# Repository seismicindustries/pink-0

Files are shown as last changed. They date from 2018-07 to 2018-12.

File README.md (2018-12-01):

<!--- View this project on [CADLAB.io](https://cadlab.io/project/1079). -->

# (s)pink-0
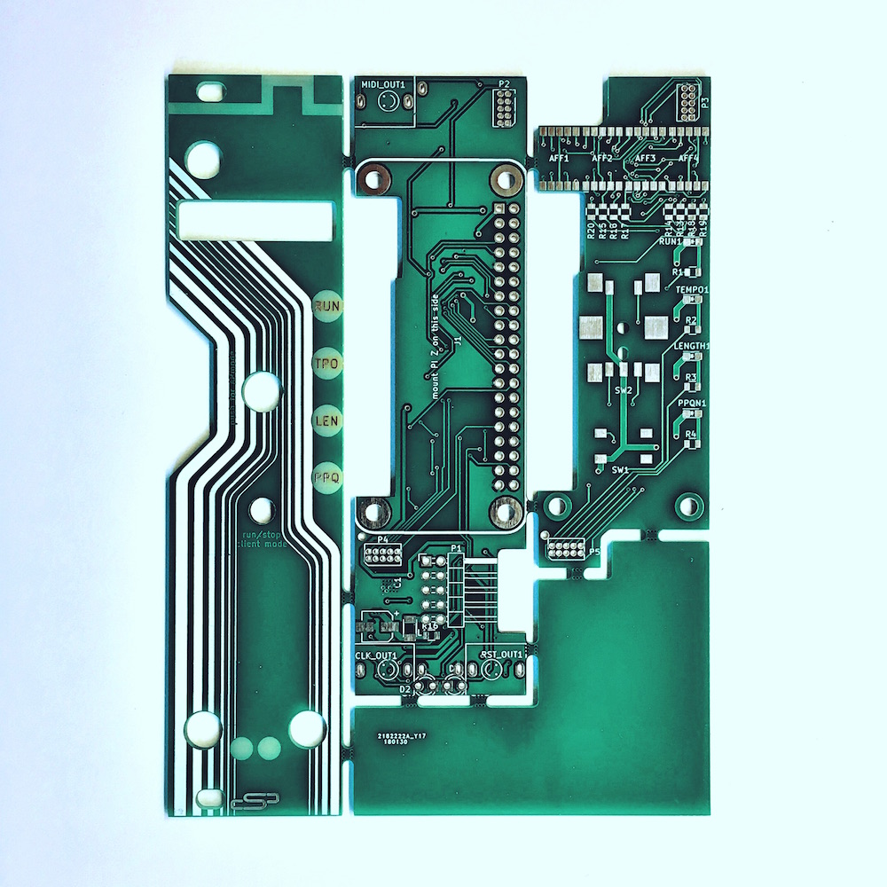
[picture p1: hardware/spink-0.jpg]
pic of the spink-0 PCB adaption

This repository contains the source code and the schematics for an Ableton Link to clock/reset converter.

And the necessary changes & hardware files for the spink-0 adaption

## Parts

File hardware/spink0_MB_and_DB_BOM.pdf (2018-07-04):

spink0 Mainboard
Refs | Value | Footprint | QTY MFR | MPN | SPR | SPN
C1 | 22u | raffilibkicad:CP_Elec_5x5.3 | 1 Panasonic | EEE-FK1C220R | Mouser | 667-EEE-FK1C220R
C6 | 22u | raffilibkicad:CP_Elec_7.3x4.3 | 1 Panasonic | EEF-CX1D220R | Mouser | 667-EEF-CX1D220R
C7 | 100n | raffilibkicad:C_0805 | 1 AVX | 08055C104KAT2A | Mouser | 581-08055C104K
C3 | 1u | raffilibkicad:C_0805 | 1 Yageo | CC0805MKY5V9BB105 Mouser | 603-CC805MKY5V9BB105
C4;C5 | 33n | raffilibkicad:C_0805 | 2 Kemet | C0805C333K5RACTU Mouser | 80-C0805C333K5R
L1 | INDUCTOR | raffilibkicad:Inductor_PSU_NLCV32T | 1 TDK | NLCV32T-R10M-PFR | Mouser | 810-NLCV32T-R10M-PFR
L3 | 6.8uH | raffilibkicad:Inductor_SRN4018TA_bourns | 1 Bourns | SRN4018TA-6R8M | Mouser | 652-SRN4018TA-6R8M
D2;D1 | LED | raffilibkicad:LED_D3.0mm | 2 Lite-On | LTL-4231N | Mouser | 859-LTL-4231N
P2;P4 | CONN_02X05 | raffilibkicad:PINHEAD_10_pin_jtag_connector 2 Amphenol FCI | 20021111-00010T4LF Mouser | 649-221111-00010T4LF
J1 | PI_ZERO | raffilibkicad:PI_ZERO | 1 | | your PI supplier
P1 | CONN_02X05 | raffilibkicad:Pin_Header_Angled_2x05_Pitch2.54mm_with_space_for_con 1 Amphenol FCI | 649-68020-110HLF | Mouser | 68020-110HLF
R16 | 100k | raffilibkicad:R_0805 | 1 Yageo | RC0805FR-07100KL | Mouser | 603-RC0805FR-07100KL
R5;R6;R21;R24;R23 | 10k | raffilibkicad:R_0805 | 5 Vishay | CRCW080510K0FKEAC Mouser | 71-CRCW080510K0FKEAC
R10;R7;R9;R8;R12;R11;R13;R4;R14;R15;R17;R18 1k | raffilibkicad:R_0805 | 12 Vishay | CRCW08051K00FKEAC Mouser | 71-CRCW08051K00FKEAC
R22 | 220 | raffilibkicad:R_0805 | 1 Bourns | CR0805-FX-2200GLF | Mouser | 652-CR0805-FX2200GLF
R2 | 40k2 | raffilibkicad:R_0805 | 1 Yageo | RC0805FR-0740K2L | Mouser | 603-RC0805FR-0740K2L
R1 | 75k | raffilibkicad:R_0805 | 1 Vishay | CRCW080575K0FKEA Mouser | 71-CRCW0805-75K-E3
R3 | 7k68 | raffilibkicad:R_0805 | 1 Yageo | RC0805FR-077K68L | Mouser | 603-RC0805FR-077K68L
Q1;Q2;Q3;Q4 | BC849 | raffilibkicad:SOT-23 | 4 | | Mouser | 771-BC849C-T/R
U1 | MP1469 | raffilibkicad:SOT-23-6 | 1 MPS | MP1469GJ-Z | Mouser | 946-MP1469GJZ
U2 | MCP6004 | raffilibkicad:TSSOP-14_4.4x5mm_Pitch0.65mm 1 Microchip Techology MCP6004-I/ST | Mouser | 579-MCP6004-I/ST
CLK_OUT1;RST_OUT1 | JACK_QINGPU | raffilibkicad:jack_qingpu | 2 | a.k.a. thonkicon
MIDI_OUT1 | TRS stereojack | raffilibkicad:jack_qingpu | 1 maybe green thonkicon or -> | Mouser | 161-3402-E
J6;J5;J8;J7 | GS3 | raffilibkicad:solderbridge | 4

spink0 Displayboard
Refs | Value | Footprint | QTY MFR | MPN | SPR | SPN
RUN1;TEMPO1;LENGTH1;PPQN1 | LED | LEDs:LED_0805 | 4 Kingbright | APHCM2012CGCK-F01 Mouser | 604-APHCM2012CGCK
AFF1;AFF2;AFF3;AFF4 | 7SEGMENTS | raffilibkicad:ACSA02_KCSA02_7segment | 4 Kingbright | ACSA02-41SGWA-F01 Mouser | 604-ACSA02-41SGWA
SW1 | SW_PUSH_SMALL_H | raffilibkicad:APEM_tactile_SMD_switch_6mm 1 APEM | ADTSM66NV | Mouser | 642-ADTSM66NV
SW2 | Rotary_Encoder_Switch raffilibkicad:ENCODER_PEC11_SMD | 1 Bourns | PEC11S-929K-S0015 | Mouser | 652-PEC11S9215KH0015
R1;R2;R3;R4;R13;R14;R15;R16;R17;R18;R19;R20 100 | raffilibkicad:R_0805 | 12 Yageo | RC0805FR-07100RL | Mouser | 603-RC0805FR-07100RL

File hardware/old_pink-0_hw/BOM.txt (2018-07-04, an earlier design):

Resistors
12x  330R 0402 (R1 - R12)
2x   750R 0402 (R15, R16)
4x   1K   0402 (R17 - R20)
2x   10K  0402 (R13, R14)

Capacitors
2x   33n 0603  (C1, C2)

Transistors
2x   MMBT3904 (T1, T2)

LEDs
3x   LED 0603 yellow
1x   LED 0603 green

Connectors
2x   Erthenvar PJ301BM
1x   2x40 pin female header

Misc
1x   Display HP QDSP6064
1x   Rotary encoder w/ pushbutton
1x   6mm tactile switch
1x   Pink-0 pcb

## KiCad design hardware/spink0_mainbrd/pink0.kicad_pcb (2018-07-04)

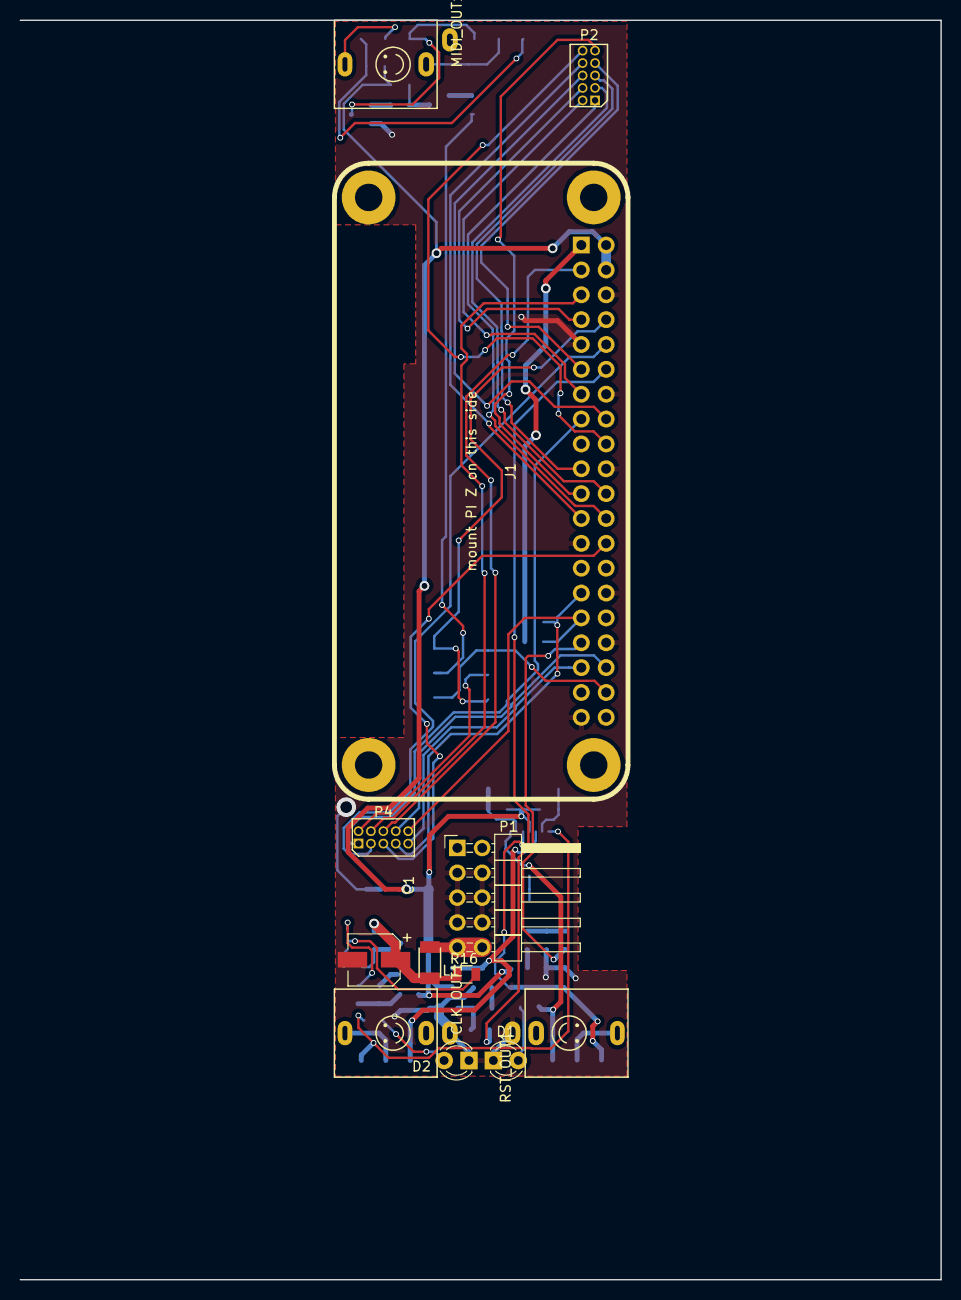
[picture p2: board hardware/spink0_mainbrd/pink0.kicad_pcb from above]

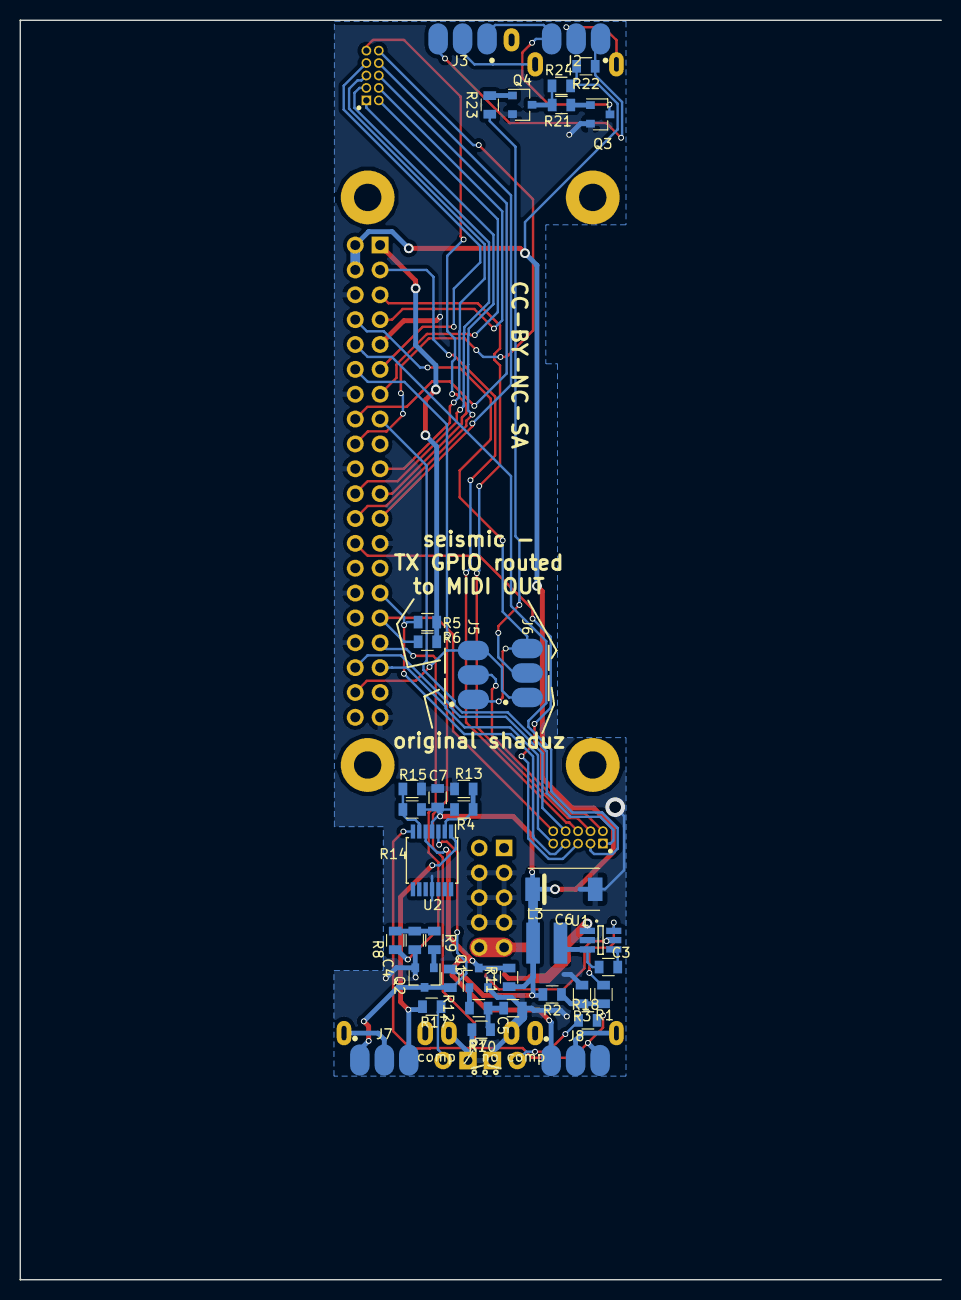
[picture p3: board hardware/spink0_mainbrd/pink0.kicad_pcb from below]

Board: 2 copper layers, 94.1 x 128.7 mm, 51 parts (39 on the bottom side), 56 nets.

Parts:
C1: 22u; CP_Elec_5x5.3
C3: 1u; C_0805
C4, C5: 33n; C_0805
C6: 22u; CP_Elec_7.3x4.3
C7: 100n; C_0805
CLK_OUT1: JACK_QINGPU; jack_qingpu
D1, D2: LED; LED_D3.0mm
J1: PI_ZERO
J2, J3, J5, J6, J7, J8: GS3; solderbridge
L1: INDUCTOR; Inductor_PSU_NLCV32T
L3: 6.8uH; Inductor_SRN4018TA_bourns
MIDI_OUT1: JACK_QINGPU; jack_qingpu
P1: CONN_02X05; Pin_Header_Angled_2x05_Pitch2.54mm_with_space_for_con
P2, P4: CONN_02X05; PINHEAD_10_pin_jtag_connector
Q1, Q2, Q3, Q4: BC849; SOT-23
R1: 75k; R_0805
R2: 40k2; R_0805
R3: 7k68; R_0805
R4, R7, R8, R9, R10, R11, R12, R13, R14, R15, R17, R18: 1k; R_0805
R5, R6, R21, R23, R24: 10k; R_0805
R16: 100k; R_0805
R22: 220; R_0805
RST_OUT1: JACK_QINGPU; jack_qingpu
U1: MP1469; SOT-23-6
U2: MCP6004; TSSOP-14_4.4x5mm_Pitch0.65mm

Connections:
+3V3: J1.1, R5.1, R6.1
+5V: C6.1, C7.2, J1.2, J1.4, L3.1, R2.2, R4.1, R11.2, R12.2, R14.1, R22.1, R24.2, U2.4
+12VA: C1.1, L1.1, R16.1, U1.1
CLK_OUT: J8.1, Q1.3, R11.1, U2.5
Earth: C1.2, C4.2, C5.2, C6.2, C7.1, CLK_OUT1.1, D1.1, D2.1, J1.6, J1.9, J1.14, J1.20, J1.25, J1.30, J1.34, J1.39, P1.3, P1.4, P1.5, P1.6, P1.7, P1.8, Q1.2, Q2.2, Q3.2, Q4.2, R3.1, R13.2, R15.2, RST_OUT1.1, U1.2, U2.11
GPIO2: J1.3, P4.6
GPIO3: J1.5, P4.4
GPIO4: J1.7, P2.4
GPIO5: J1.29, P4.7, R5.2
GPIO6: J1.31, P4.10, R6.2
GPIO7: J1.26, P4.5
GPIO8: J1.24, P2.1
GPIO9: J1.21, P2.9
GPIO10: J1.19, P2.5
GPIO11: J1.23, P2.8
GPIO14: J1.8, J5.1, J6.3
GPIO15: J1.10, P4.3
GPIO16: J1.36, P4.8
GPIO17: J1.11, P2.7
GPIO19: J1.35, P4.9
GPIO20: J1.38, J5.3, J6.1
GPIO22: J1.15, P4.1
GPIO23: J1.16, P2.6
GPIO24: J1.18, P2.10
GPIO25: J1.22, P2.3
GPIO27: J1.13, P2.2
unnamed: C3.1, L3.2, U1.3
unnamed: C3.2, U1.4
unnamed: C4.1, R8.1, R9.2
unnamed: C5.1, R7.1, R10.2
unnamed: CLK_OUT1.3, J8.2
unnamed: D1.2, R17.1
unnamed: D2.2, R18.1
unnamed: J2.1, J3.3, R22.2
unnamed: J2.2, MIDI_OUT1.3
unnamed: J2.3, J3.1, Q3.3
unnamed: J3.2, MIDI_OUT1.2
unnamed: J6.2, R23.2
unnamed: J7.2, RST_OUT1.3
unnamed: J7.3, R17.2, U2.1
unnamed: J8.3, R18.2, U2.7
unnamed: L1.2, P1.9, P1.10
unnamed: Q1.1, R10.1
unnamed: Q2.1, R9.1
unnamed: Q3.1, R21.1
unnamed: Q4.1, R23.1
unnamed: Q4.3, R21.2, R24.1
unnamed: R1.1, U1.6
unnamed: R1.2, R2.1, R3.2
unnamed: R4.2, R13.1, U2.2
unnamed: R14.2, R15.1, U2.6
unnamed: R16.2, U1.5
PWMA_L: J1.12, R7.2
PWMA_R: J1.33, R8.2
RST_OUT: J7.1, Q2.3, R12.1, U2.3
T_LED: J5.2, P4.2

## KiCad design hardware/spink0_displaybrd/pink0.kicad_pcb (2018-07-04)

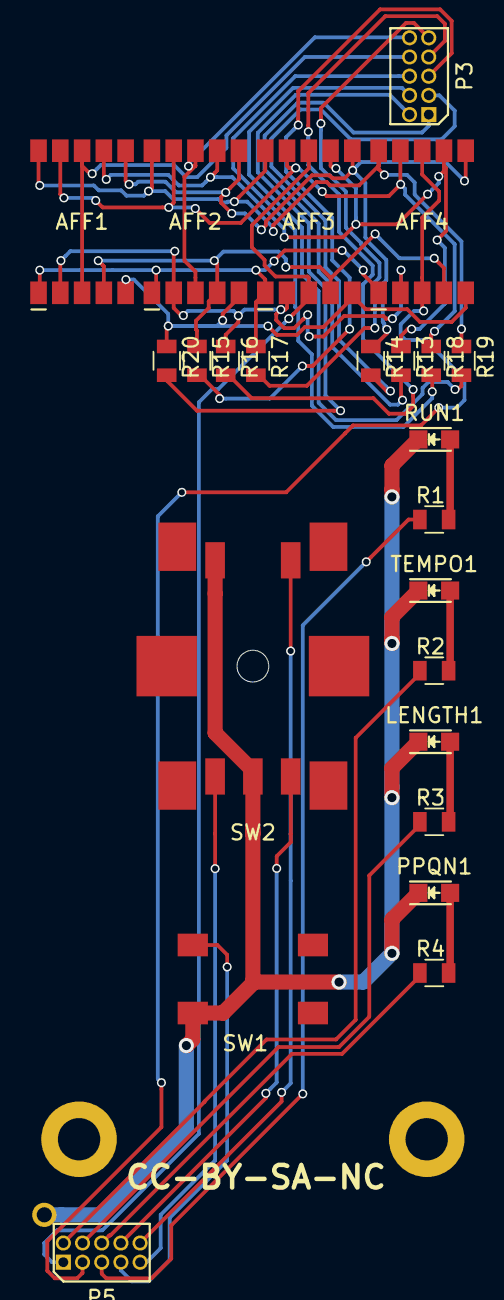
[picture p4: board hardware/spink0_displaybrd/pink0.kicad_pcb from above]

Board: 2 copper layers, 24 parts (0 on the bottom side), 33 nets.

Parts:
AFF1, AFF2, AFF3, AFF4: 7SEGMENTS; ACSA02_KCSA02_7segment
LENGTH1: LED; LED_0805
P3, P5: CONN_02X05; PINHEAD_10_pin_jtag_connector
PPQN1: LED; LED_0805
R1, R2, R3, R4, R13, R14, R15, R16, R17, R18, R19, R20: R; R_0805
RUN1: LED; LED_0805
SW1: SW_PUSH_SMALL_H; APEM_tactile_SMD_switch_6mm
SW2: Rotary_Encoder_Switch; ENCODER_PEC11_SMD
TEMPO1: LED; LED_0805

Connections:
A: AFF1.7, AFF2.7, AFF3.7, AFF4.7, R13.1
B: AFF1.6, AFF2.6, AFF3.6, AFF4.6, R14.1
C: AFF1.4, AFF2.4, AFF3.4, AFF4.4, R15.1
D: AFF1.2, AFF2.2, AFF3.2, AFF4.2, R16.1
DP: AFF1.5, AFF2.5, AFF3.5, AFF4.5, R20.1
E: AFF1.1, AFF2.1, AFF3.1, AFF4.1, R17.1
Earth: LENGTH1.1, PPQN1.1, RUN1.1, SW1.2, SW2.2, SW2.5, TEMPO1.1
F: AFF1.9, AFF2.9, AFF3.9, AFF4.9, R18.1
G: AFF1.10, AFF2.10, AFF3.10, AFF4.10, R19.1
GPIO2: P5.6, R4.1
GPIO3: P5.4, R3.1
GPIO4: P3.4, R19.2
GPIO5: P5.7, SW1.1
GPIO6: P5.10, SW2.4
GPIO7: P5.5, R1.1
GPIO8: P3.1, R13.2
GPIO9: P3.9, R17.2
GPIO10: P3.5, R15.2
GPIO11: AFF1.3, AFF1.8, P3.8
GPIO15: AFF4.3, AFF4.8, P5.3
GPIO16: P5.8, SW2.3
GPIO17: P3.7, R16.2
GPIO19: P5.9, SW2.1
GPIO22: AFF3.3, AFF3.8, P5.1
GPIO23: P3.6, R18.2
GPIO24: AFF2.3, AFF2.8, P3.10
GPIO25: P3.3, R14.2
GPIO27: P3.2, R20.2
unnamed: LENGTH1.2, R3.2
unnamed: PPQN1.2, R4.2
unnamed: R1.2, RUN1.2
unnamed: R2.2, TEMPO1.2
T_LED: P5.2, R2.1

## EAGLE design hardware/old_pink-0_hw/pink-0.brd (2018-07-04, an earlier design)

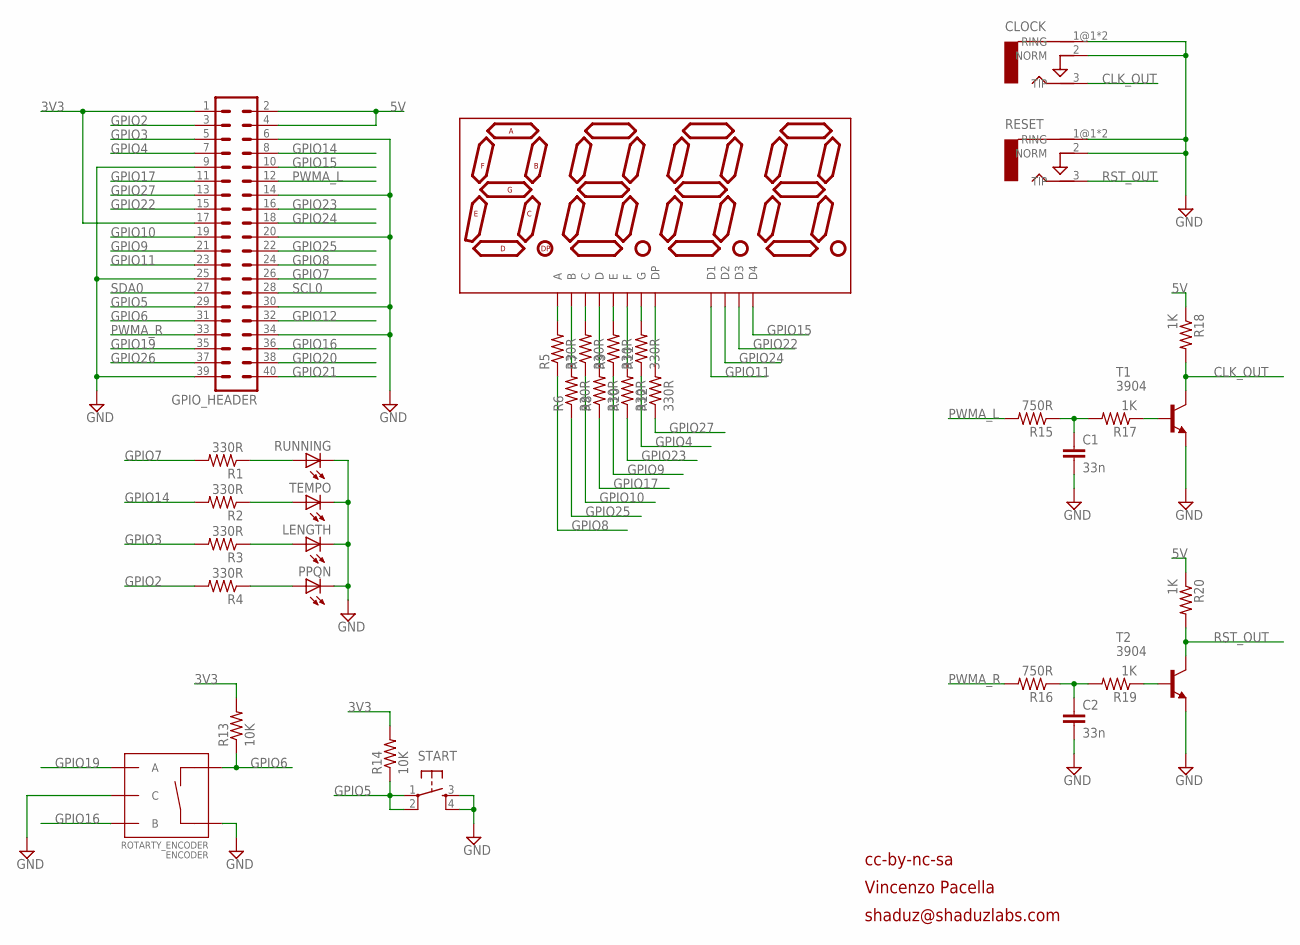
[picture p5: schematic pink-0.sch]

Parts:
C1, C2: 33n; 0603-CAP
CLOCK: AUDIO-JACKERTHENVAR; ERTHENVAR-JACK
DISP1: QDSP6064; DIL12
ENCODER: ROTARTY_ENCODER; ROTARY_ENC_PLAIN
GPIO_HEADER: PIZERO_THROUGH_HOLE; PIZERO_THOUGH_HOLE
LENGTH: LED0603; LED-0603
PPQN: LED0603; LED-0603
R1, R2, R3, R4, R5, R6, R7, R8, R9, R10, R11, R12: 330R; R0402
R13, R14: 10K; R0402
R15, R16: 750R; R0402
R17, R18, R19, R20: 1K; R0402
RESET: AUDIO-JACKERTHENVAR; ERTHENVAR-JACK
RUNNING: LED0603; LED-0603
START: TAC_SWITCHPTH; TACTILE-PTH
T1, T2: 3904; SOT23-BEC
TEMPO: LED0603; LED-0603

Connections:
3V3: GPIO_HEADER.1, GPIO_HEADER.17, R13.2, R14.2
5V: GPIO_HEADER.2, GPIO_HEADER.4, R18.1, R20.1
CLK_OUT: CLOCK.3 (TIP), R18.2, T1.C
GND: C1.2, C2.2, CLOCK.1@1 (RING), CLOCK.1@2 (RING), CLOCK.2 (NORM), ENCODER.C, ENCODER.SW+, GPIO_HEADER.6, GPIO_HEADER.9, GPIO_HEADER.14, GPIO_HEADER.20, GPIO_HEADER.25, GPIO_HEADER.30, GPIO_HEADER.34, GPIO_HEADER.39, LENGTH.C, PPQN.C, RESET.1@1 (RING), RESET.1@2 (RING), RESET.2 (NORM), RUNNING.C, START.3, START.4, T1.E, T2.E, TEMPO.C
GPIO2: GPIO_HEADER.3, R4.2
GPIO3: GPIO_HEADER.5, R3.2
GPIO4: GPIO_HEADER.7, R11.1
GPIO5: GPIO_HEADER.29, R14.1, START.1, START.2
GPIO6: ENCODER.SW-, GPIO_HEADER.31, R13.1
GPIO7: GPIO_HEADER.26, R1.2
GPIO8: GPIO_HEADER.24, R5.1
GPIO9: GPIO_HEADER.21, R9.1
GPIO10: GPIO_HEADER.19, R7.1
GPIO11: DISP1.1 (D1), GPIO_HEADER.23
GPIO12: GPIO_HEADER.32
GPIO14: GPIO_HEADER.8, R2.2
GPIO15: DISP1.6 (D4), GPIO_HEADER.10
GPIO16: ENCODER.B, GPIO_HEADER.36
GPIO17: GPIO_HEADER.11, R8.1
GPIO19: ENCODER.A, GPIO_HEADER.35
GPIO20: GPIO_HEADER.38
GPIO21: GPIO_HEADER.40
GPIO22: DISP1.4 (D3), GPIO_HEADER.15
GPIO23: GPIO_HEADER.16, R10.1
GPIO24: DISP1.10 (D2), GPIO_HEADER.18
GPIO25: GPIO_HEADER.22, R6.1
GPIO26: GPIO_HEADER.37
GPIO27: GPIO_HEADER.13, R12.1
unnamed: DISP1.12 (A), R5.2
unnamed: DISP1.11 (B), R6.2
unnamed: DISP1.3 (C), R7.2
unnamed: DISP1.8 (D), R8.2
unnamed: R1.1, RUNNING.A
unnamed: R2.1, TEMPO.A
unnamed: DISP1.2 (E), R9.2
unnamed: DISP1.9 (F), R10.2
unnamed: DISP1.7 (G), R11.2
unnamed: DISP1.5 (DP), R12.2
unnamed: R19.1, T2.B
unnamed: R17.1, T1.B
unnamed: C1.1, R15.1, R17.2
unnamed: LENGTH.A, R3.1
unnamed: PPQN.A, R4.1
unnamed: C2.1, R16.1, R19.2
PWMA_L: GPIO_HEADER.12, R15.2
PWMA_R: GPIO_HEADER.33, R16.2
RST_OUT: R20.2, RESET.3 (TIP), T2.C
SCL0: GPIO_HEADER.28
SDA0: GPIO_HEADER.27

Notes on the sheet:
cc-by-nc-sa
Vincenzo Pacella
shaduz@shaduzlabs.com

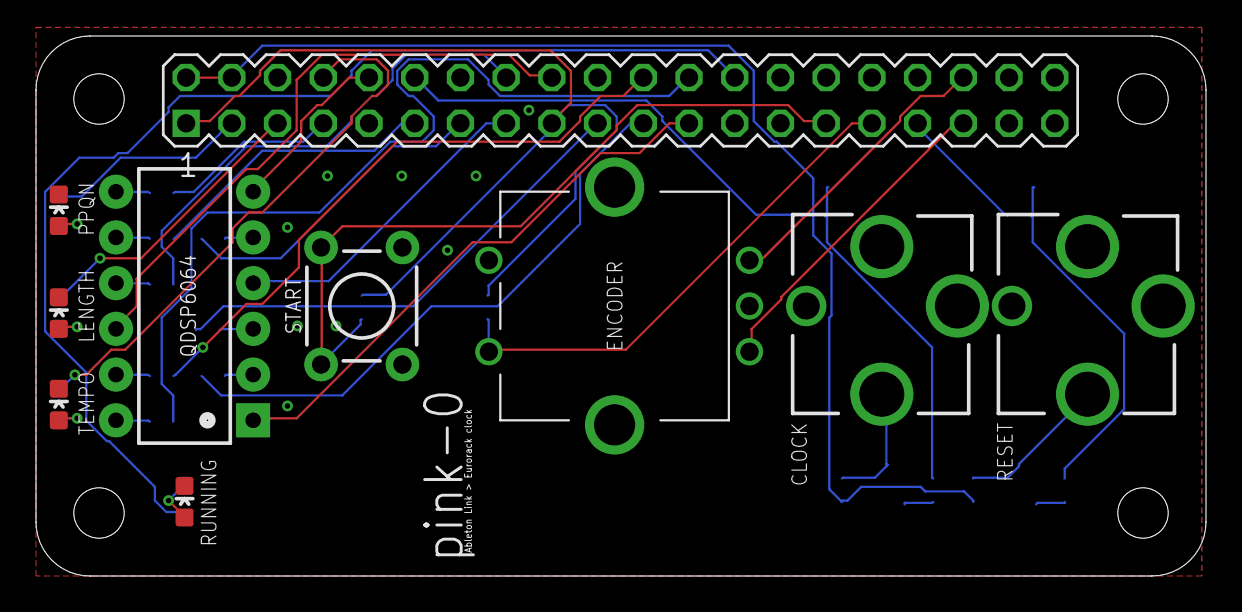
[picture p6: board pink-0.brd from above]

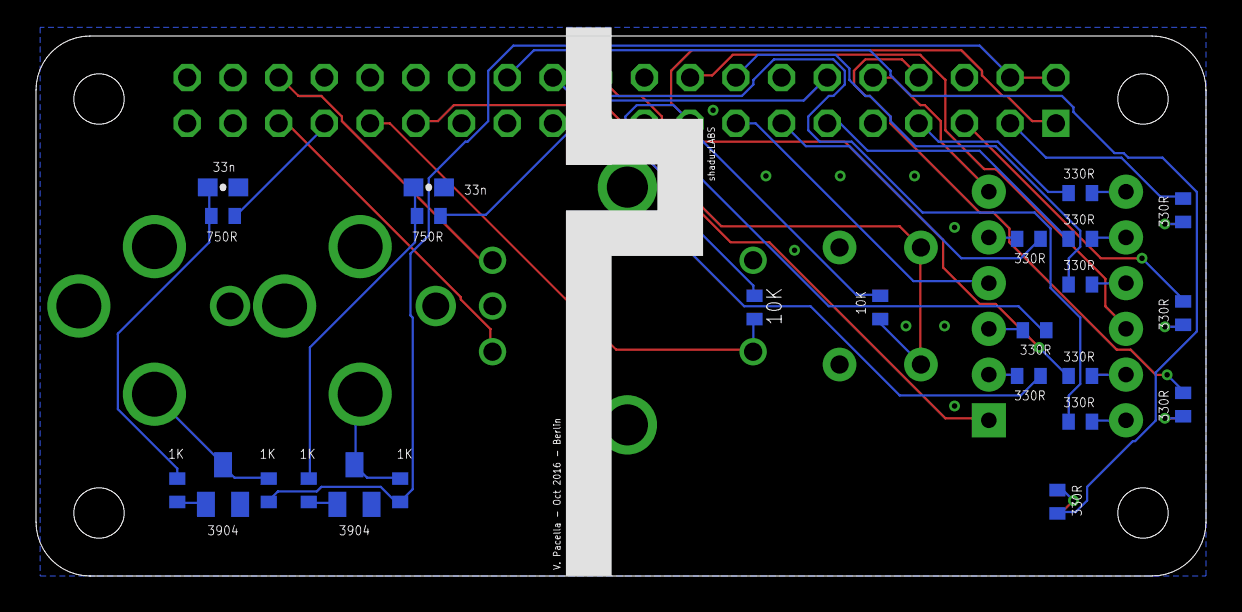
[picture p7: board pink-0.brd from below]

Board: 2 copper layers, 65.0 x 30.0 mm, 34 parts (24 on the bottom side), 43 nets.

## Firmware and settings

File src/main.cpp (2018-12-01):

/*
        ##########    Copyright (C) 2016 Vincenzo Pacella
        ##      ##    Distributed under MIT license, see file LICENSE
        ##      ##    or <http://opensource.org/licenses/MIT>
        ##      ##
##########      #############################################################
shaduzlabs.com #####*/

#include <memory>
#include <tuple>

#ifdef __linux__

#include <errno.h>
#include <fcntl.h>
#include <stdio.h>
#include <stdlib.h>
#include <string.h>
#include <sys/stat.h>
#include <sys/types.h>
#include <syslog.h>
#include <unistd.h>

#endif // __linux__

#include "Audio.h"
#include "Pink.h"

#include "ui/UserInterfaceNone.h"
#ifdef UI_USE_WEBSOCKET
#include "ui/UserInterfaceWebSocket.h"
#endif
#ifdef UI_USE_RASPBERRY_PI_ZERO
#include "ui/UserInterfacePiZero.h"
#endif

#define DAEMON_NAME "pinkd"

//--------------------------------------------------------------------------------------------------

#ifdef __linux__

int pidFilehandle;

#endif // __linux__

//--------------------------------------------------------------------------------------------------

#ifdef __linux__

void daemonShutdown()
{
  close(pidFilehandle);
}

#endif // __linux__

//--------------------------------------------------------------------------------------------------

#ifdef __linux__

void signalHandler(int sig)
{
  switch (sig)
  {
    case SIGHUP:
      syslog(LOG_WARNING, "Received SIGHUP signal.");
      break;
    case SIGINT:
    case SIGTERM:
      syslog(LOG_INFO, "Daemon exiting");
      daemonShutdown();
      exit(EXIT_SUCCESS);
      break;
    default:
      syslog(LOG_WARNING, "Unhandled signal %s", strsignal(sig));
      break;
  }
}

#endif // __linux__

//--------------------------------------------------------------------------------------------------

static void daemonize(const char* runDir_, const char* pidFile_)
{
#ifndef __linux__
  std::ignore = runDir_;
  std::ignore = pidFile_;
#else
  /* Our process ID and Session ID */
  pid_t pid, sid;
  int i;
  char str[10];
  struct sigaction newSigAction;
  sigset_t newSigSet;

  /* Check if parent process id is set */
  if (getppid() == 1)
  {
    /* PPID exists, therefore we are already a daemon */
    return;
  }

  sigemptyset(&newSigSet);
  sigaddset(&newSigSet, SIGCHLD);           /* ignore child - i.e. we don't need to wait for it */
  sigaddset(&newSigSet, SIGTSTP);           /* ignore Tty stop signals */
  sigaddset(&newSigSet, SIGTTOU);           /* ignore Tty background writes */
  sigaddset(&newSigSet, SIGTTIN);           /* ignore Tty background reads */
  sigprocmask(SIG_BLOCK, &newSigSet, NULL); /* Block the above specified signals */

  /* Set up a signal handler */
  newSigAction.sa_handler = signalHandler;
  sigemptyset(&newSigAction.sa_mask);
  newSigAction.sa_flags = 0;

  /* Signals to handle */
  sigaction(SIGHUP, &newSigAction, NULL);  /* catch hangup signal */
  sigaction(SIGTERM, &newSigAction, NULL); /* catch term signal */
  sigaction(SIGINT, &newSigAction, NULL);  /* catch interrupt signal */

  /* Fork off the parent process */
  pid = fork();
  if (pid < 0)
  {
    exit(EXIT_FAILURE);
  }
  /* If we got a good PID, then we can exit the parent process. */
  if (pid > 0)
  {
    exit(EXIT_SUCCESS);
  }

  /* Change the file mode mask */
  umask(027);

  /* Create a new SID for the child process */
  sid = setsid();
  if (sid < 0)
  {
    /* Log the failure */
    syslog(LOG_ERR, "ERROR: Failed to create a new session");
    exit(EXIT_FAILURE);
  }

  /* Close out the open file descriptors */
  for (int fd = sysconf(_SC_OPEN_MAX); fd > 0; fd--)
  {
    close(fd);
  }

  /* Route I/O connections */

  /* Open STDIN */
  i = open("/dev/null", O_RDWR);

  /* STDOUT */
  dup(i);

  /* STDERR */
  dup(i);

  if ((chdir(runDir_)) < 0)
  {
    syslog(LOG_ERR, "ERROR: Failed to change the working directory to %s", runDir_);
    exit(EXIT_FAILURE);
  }

  /* Ensure only one copy */
  pidFilehandle = open(pidFile_, O_RDWR | O_CREAT, 0600);

  if (pidFilehandle == -1)
  {
    /* Couldn't open lock file */
    syslog(LOG_INFO, "Could not open PID lock file %s, exiting", pidFile_);
    exit(EXIT_FAILURE);
  }

  /* Try to lock file */
  if (lockf(pidFilehandle, F_TLOCK, 0) == -1)
  {
    /* Couldn't get lock on lock file */
    syslog(LOG_INFO, "Could not lock PID lock file %s, exiting", pidFile_);
    exit(EXIT_FAILURE);
  }

  /* Get and format PID */
  sprintf(str, "%d\n", getpid());

  /* write pid to lockfile */
  write(pidFilehandle, str, strlen(str));
#endif
}

//--------------------------------------------------------------------------------------------------

class ScopedLog
{
public:
  ScopedLog()
  {
#ifdef __linux__
    setlogmask(LOG_UPTO(LOG_INFO));
    openlog(DAEMON_NAME, LOG_CONS | LOG_PERROR, LOG_USER);
#endif // __linux__
  }
  ~ScopedLog()
  {
#ifdef __linux__
    closelog();
#endif // __linux__
  }

  void info(const char* message_)
  {
#ifdef __linux__
    syslog(LOG_INFO, message_);
#else
    std::cout << DAEMON_NAME << ": " << message_ << std::endl;
#endif
  }

  void exception(const std::exception& e_)
  {
#ifdef __linux__
    syslog(LOG_ERR, "ERROR: An exception occurred  (%s)", e_.what());
#else
    std::cerr << "An exception occurred: " << e_.what() << std::endl;
#endif
  }
};

//--------------------------------------------------------------------------------------------------

using namespace sl;
using namespace sl::pi;

int main(int argc_, char* argv_[])
{
  ScopedLog log;

  log.info("daemon starting");
  if (argc_ != 2 || std::string(argv_[1]) != "no-daemon")
  {
    daemonize("/tmp/", "/var/run/pinkd.pid");
  }

  std::shared_ptr<Pink> pink(new Pink(120., 4., 1.0));

  try
  {
    std::shared_ptr<Pink> pink(new Pink(120., 4., 1.0));

#ifdef UI_USE_WEBSOCKET
    UserInterfaceWebSocket webSocket(pink);
#endif
#ifdef UI_USE_RASPBERRY_PI_ZERO
    UserInterfacePiZero zero(pink);
#endif
#if !defined(UI_USE_RASPBERRY_PI_ZERO) && !defined(UI_USE_WEBSOCKET)
    UserInterfaceNone zero(pink);
#endif

    log.info("daemon running");

    while (true)
    {
      std::this_thread::sleep_for(std::chrono::milliseconds(10));
    }
  }
  catch (const std::exception& e)
  {
    log.exception(e);
  }

  log.info("daemon terminated");

  return 0;
}

//--------------------------------------------------------------------------------------------------

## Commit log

2018-07-04 commit all changes from SI - (add spink hw files, addnet.php, modified UserInterfacePiZero.cpp, modeswitch stuff)
    [pink-0.brd, pink-0.sch, pink0.kicad_pcb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]
2018-07-04 modeswitch DIR cleaned, BOM pdf added, comment out cadlab

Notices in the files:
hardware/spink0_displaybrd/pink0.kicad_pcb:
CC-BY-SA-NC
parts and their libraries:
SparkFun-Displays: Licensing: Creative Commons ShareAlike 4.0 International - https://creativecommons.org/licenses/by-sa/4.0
